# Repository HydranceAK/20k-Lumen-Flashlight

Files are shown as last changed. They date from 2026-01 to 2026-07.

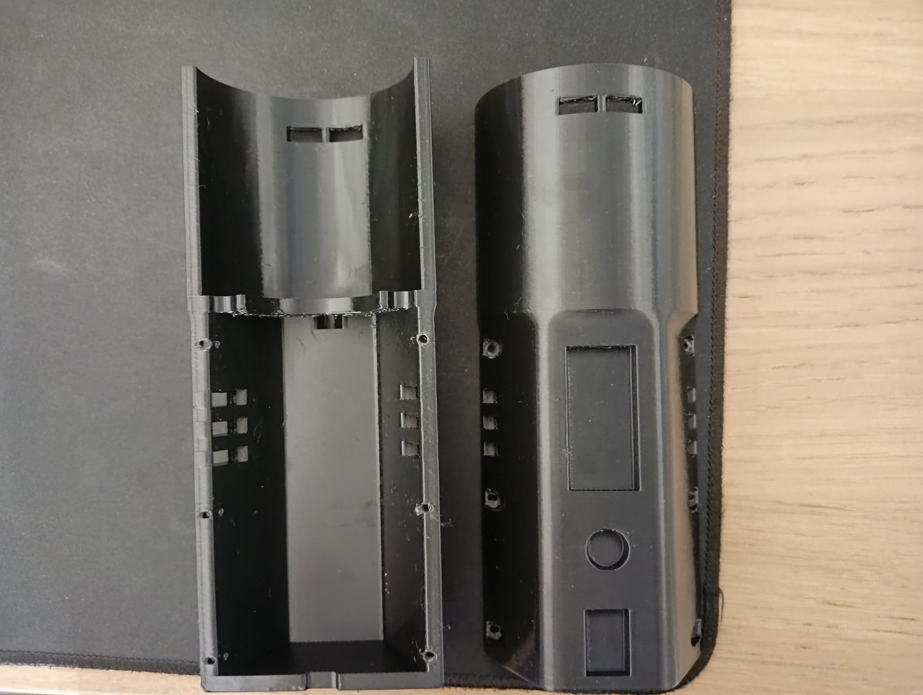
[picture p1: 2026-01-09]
Images/WhatsApp Image 2026-01-09 at 8.15.24 AM.jpeg

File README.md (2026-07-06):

**3d Printed Flashlight - Aprox 20k Lumens**

This is a fully 3d printed flashlight I've designed and created from scratch. Designed and Engineered by *Hydrance*

<b>Features:</b>

* Battery Indicator
* Estimated 30 min life
* Estimated 20k Lumen
* USB-C Charging
* Water Resistant (NOT WATERPROOF!)
* Much cheaper than similar commercial products (they go up to $300)
* As cheap as possible ($100)
* 

Printing Notes:

I recommend you print with at the least PETG filament, do NOT use PLA, its heat resistance is really low and the flashlight will DEFFINITELY melt or even catch fire if you run it for too long. If you have the budget and you want something indestructible in all senses, use PA6-CF or PA12-CF. Their heat resistance is off the charts, and strength is exceptional.

Everything will be able to be printed on the Bambu Lab a1. You can print it on even smaller printers like the a1 mini, ender 3 pro, or more. The parts are under 100mm in all dimensions. 

**DISCLAIMERS:**

leds CAN be really bright and harmful to stare at, can cause eye damage, please use with care.

leds WILL get extremely hot, please do not touch with bare hands while or less than 5 minutes after running.

Always use in cool environment to reduce the risk of meltdown.

I am not responsible for any damage, injury, or misuse involving this design. 

Bill of Materials:

- USB C Charing chip. Needed to charge the batteries
- Main switch. High current and will be used for the LEDS
- Tiny Switch. Low current switch, will be used for the battery indicator.
- Battery Indicator. Used to show the battery percentage level.
- Fan. Used to cool the LEDs and heatsink
- Heatsink. Absorbs the heat from the LEDs
- Batteries
- LEDs. Main source of light
- Reflective Cones. Used to concentrate the light from the LEDs onto one place.

In detailed description (all prices in CAD):



**Contact**

**For permissions, questions, or collaboration, contact me at:**

**Email: abdusamaku@gmail.com**

**YouTube: https://youtube.com/@HydranceYT**





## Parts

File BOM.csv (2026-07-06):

Quantity | Price_USD | Item_Description | Notes | URL
1 | 1.9 | Charging Chip |  | https://www.aliexpress.com/item/1005004846748321.html
10 | 6.67 | Switch | cant purchase one | https://www.aliexpress.com/item/1005007396573433.html
1 | 3.18 | Switch |  | https://www.aliexpress.com/item/1005006953954542.html
1 | 2.99 | Battery Level Indicator |  | https://www.aliexpress.com/item/1005008464466886.html
1 | 11.68 | Fan |  | https://www.aliexpress.com/item/1005008579692532.html
2 | 17.69 | Batteries |  | https://www.aliexpress.com/item/1005008019057031.html
5 | 28.0 | LEDs |  | https://www.aliexpress.com/item/1005006727275886.html
5 | 12.0 | Reflective Cones |  | https://www.aliexpress.com/item/1005005841167657.html
1 | 12.0 | Heatsink |  | https://www.aliexpress.com/item/1005005364176768.html

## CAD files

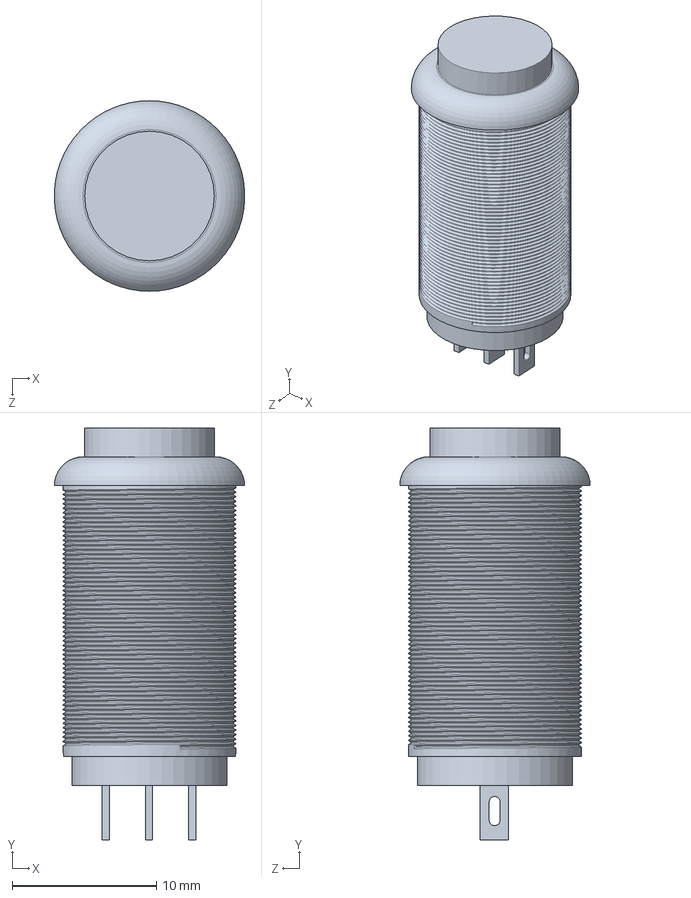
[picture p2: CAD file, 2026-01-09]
CAD Files/Solidworks Files/Micro Switch.SLDPRT
13.2 x 28.6 x 13.2 mm

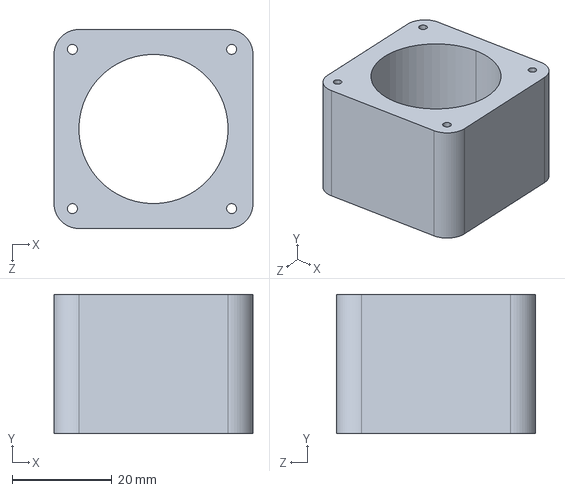
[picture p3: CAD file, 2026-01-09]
CAD Files/STEP Files/Fan.STEP
40.0 x 28.0 x 40.0 mm

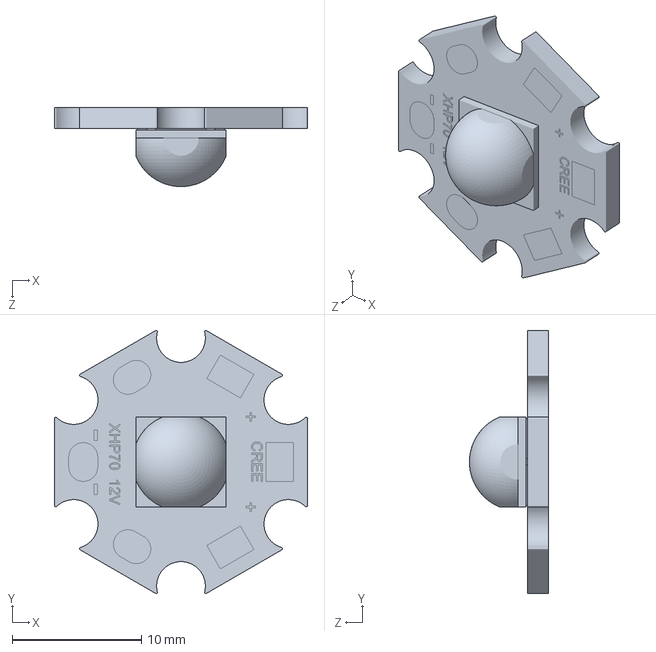
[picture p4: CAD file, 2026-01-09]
CAD Files/Solidworks Files/LED.SLDPRT
19.6 x 20.4 x 6.13 mm

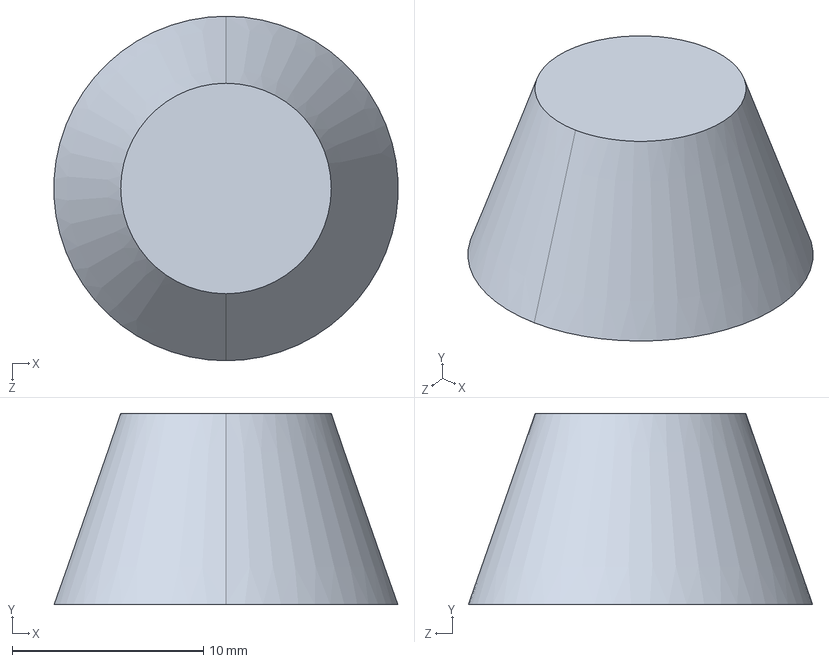
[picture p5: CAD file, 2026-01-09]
CAD Files/STEP Files/Cone.STEP
18.0 x 10.0 x 18.0 mm

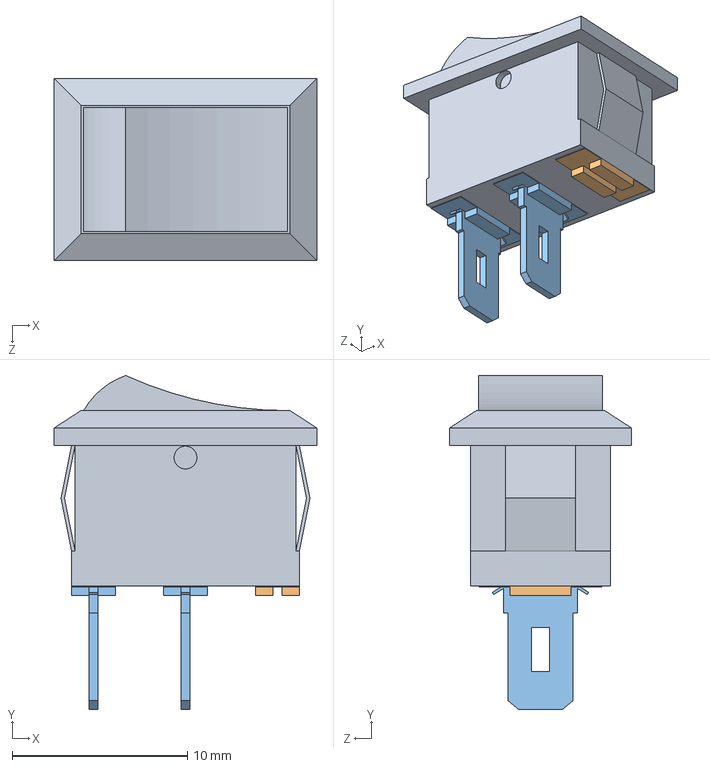
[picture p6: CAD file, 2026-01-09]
CAD Files/Solidworks Files/SwitchOnOff.STEP
15.0 x 19.1 x 10.4 mm

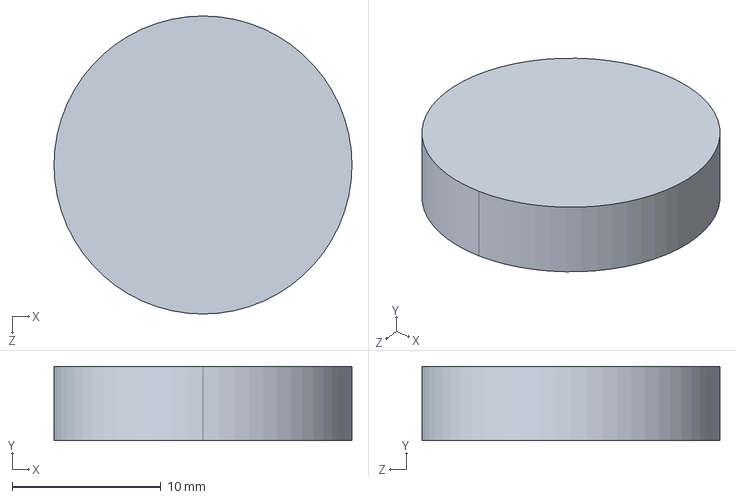
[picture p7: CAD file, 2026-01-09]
CAD Files/STEP Files/Top.STEP
20.0 x 5.00 x 20.0 mm

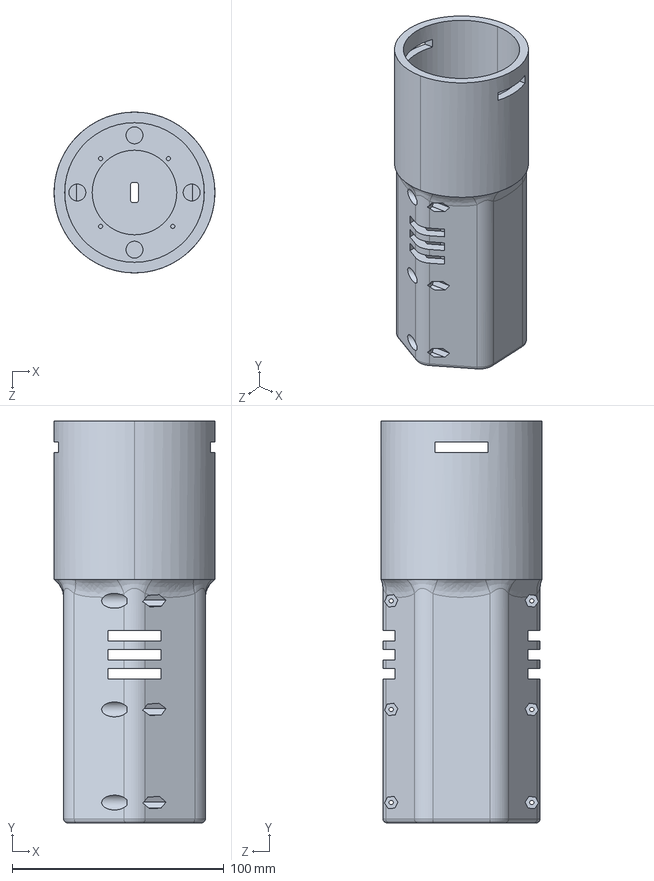
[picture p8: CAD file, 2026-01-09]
CAD Files/STEP Files/Case Upper Piece.STEP
76.0 x 190.0 x 76.0 mm

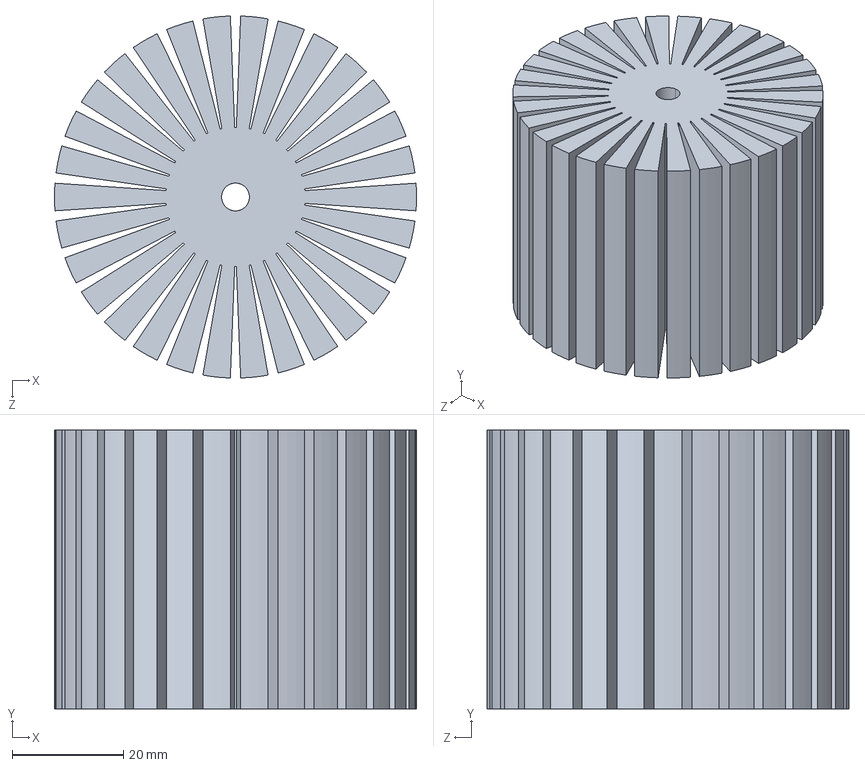
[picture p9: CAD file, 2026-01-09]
CAD Files/STEP Files/Heatsink.STEP
65.0 x 50.0 x 65.0 mm

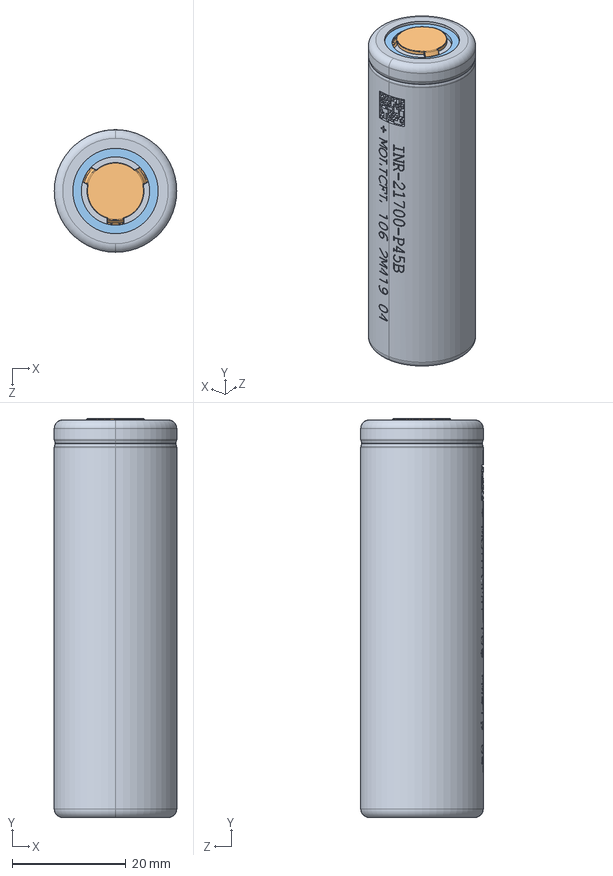
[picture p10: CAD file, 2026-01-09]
CAD Files/STEP Files/21700 Battery.STEP
21.6 x 70.2 x 21.6 mm

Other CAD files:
CAD Files/STEP Files/Cone_asm_1.STEP
CAD Files/STEP Files/Main Assembly.STEP
CAD Files/STEP Files/Cone_asm.STEP
CAD Files/Solidworks Files/21700 Battery.SLDPRT
CAD Files/Solidworks Files/Case Upper Piece.SLDPRT
CAD Files/Solidworks Files/Cone.SLDASM
CAD Files/Solidworks Files/Fan.SLDPRT
CAD Files/Solidworks Files/Heatsink.SLDPRT
CAD Files/Solidworks Files/Main Assembly.SLDASM

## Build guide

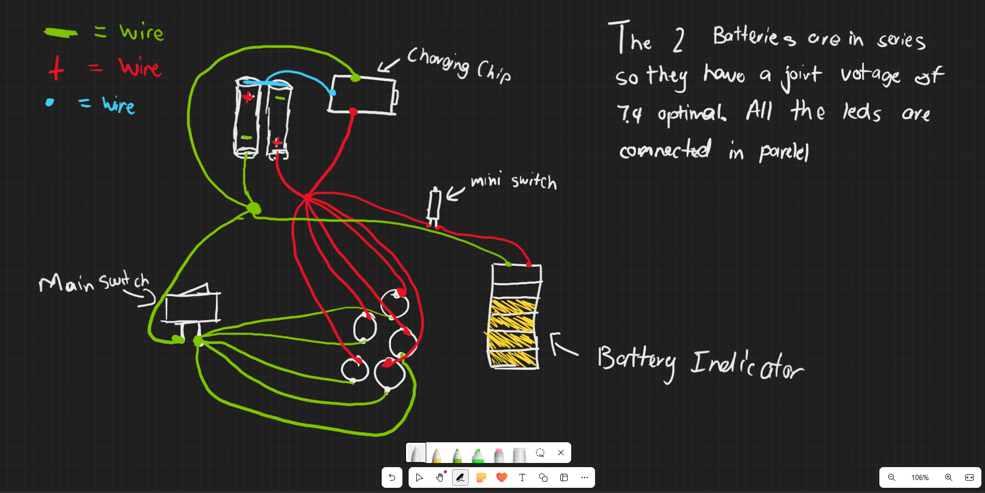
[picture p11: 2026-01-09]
Wiring Diagram.png

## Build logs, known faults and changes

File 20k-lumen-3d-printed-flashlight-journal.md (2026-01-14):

<!--
  This journal is auto generated by Hack Club Blueprint.
-->

## 1/8/2026 8:14 PM - Created the Main Case  

_Time spent: 2.0h_  

Designed the case. I went for a hexagon handle and a circle front, where the heatsink will sit. 

I created a hole for the main switch, a hole for the indicator switch, and a hole for the battery indicator. 6 screw holes to put the case together (it will be two different parts).

Im going to design the heatsink and other components next.




## 1/8/2026 8:16 PM - Added some air holes  

_Time spent: 0.5h_  

Just remembered I need somewhere for the air to actually go so I added some cut outs at the top where the air can escape. I might add some more on the side if needed.



## 1/8/2026 8:18 PM - Designed the fan  

_Time spent: 0.5h_  

Super basic design, but gets the purpose done, all I need to know is how much space the fan will go, and where the screw holes will fit. No need to waste too much time added unnecessary details.. 



## 1/8/2026 8:24 PM - Designed the Heatsink  

_Time spent: 0.5h_  

Made a CAD for the heatsink too. Once again, nothing too crazy, I tried to make it as accurate to the real one, ill put a few images of those too. Let me know how it looks.




## 1/8/2026 8:26 PM - Made the main assembly   

_Time spent: 0.5h_  

I put everything I got so far into an assembly so that I can see how everything fits together. Looks good so far, I think Ill have to add some grips on the handle part so it isn't slippery, but i think its fine for now. 



## 1/8/2026 8:49 PM - Designed the Reflective Cone  

_Time spent: 0.5h_  

I designed the reflective cones that will go on the leds in CAD so I can once again put everything together. Ill put an image of the reference just for fun. 

  

## 1/8/2026 8:49 PM - Refurbished the Case  

_Time spent: 1.0h_  

I added intake holes for the air / fan. 3 on each side, 5mm thich, * 3 = 15mm holes, 25mm width, think it should be more than enough air flow. Case really looks to be coming along good.



## 1/8/2026 8:52 PM - Made of a rough estimate of the stuff Ill need  

_Time spent: 0.5h_  

Im trying to make this as budget as possible, while still making it commercial grade like the other ones out there.

I found the cheapest parts for everything, and on aliexpress of course cause it's extremely cheap there, compared to other places at least. 



So far that's all I think ill need. 

## 1/8/2026 9:00 PM - Edited the case   

_Time spent: 0.5h_  

Added some circular holes, 4 to be exact, inside of the case so that wires can route from the LEDs on the heatsink to the main hub inside of the case. 



## 1/8/2026 9:41 PM - Completed the BOM, JOURNAL, and README Files  

_Time spent: 2.0h_  

Spent a whole bunch of time making an in detailed README files with all the main details, a BOM files with each components, its price, and information, along with a JOURNAL files with pretty much everything ive journaled so far.



Ill update the CAD files folder with the STEP and Solidworks files once ive completed my first prototypes.  

## 1/8/2026 9:55 PM - Created The Wiring Diagram  

_Time spent: 1.5h_  

Researched about the battery indicator, the charging chip, the batteries, and the LEDs. I made a pretty basic wiring diagram, not the prettiest but it gets the message across. 



## 1/8/2026 10 PM - Split the Case Into 2 and Refurbished   

_Time spent: 1.5h_  

I fixed all the clearances, added holes, and finalized the case. I then split it into 2 pieces so that it prints in two different pieces that you can easily screw together. This way its accessible you can can actually work on it and solder the pieces with ease. 



## 1/9/2026 5:21 AM - Printed a prototype  

_Time spent: 6.5h_  

I printed a prototype to get the feel and look for it. I ended up seeing some errors and miscalculations.

first, the screw holes were way too tight, they should be 3mm diameter not 2.

second, the USB-C chip hole would not fit the chip properly due to some minor miscalculations.

third, there was a major error in the holes for the battery indicator and switches, i have no idea how it happened but the hole just didn't fully cut through.

Im going to fix all the issues and finalize the design. 

WhatsApp Image 2026-01-09 at 8.15.24 AM

## 1/9/2026 5:30 AM - Created a CAD for the USB-C Charging Chip  

_Time spent: 0.5h_  

I designed a basic but accurate cad for the USB-C charging chip.  I can put this in my final design so that I don't make calculation errors like last time. 



## 1/9/2026 5:38 AM - All issues fixed  

_Time spent: 1.0h_  

All the issues have been fixed and here is what my final prototype is looking like:



I added in design supports for the air holes so that bambu slicer doesn't add massive support and waste filament.  

## 1/9/2026 5:46 AM - Prepared the 3MF Files  

_Time spent: 0.5h_  

I added manual tree supports where needed and prepared the sliced file and readied it for printing.

 

I used manual support because automatic was adding it everywhere where you didn't really need it and it would just waste filament.
